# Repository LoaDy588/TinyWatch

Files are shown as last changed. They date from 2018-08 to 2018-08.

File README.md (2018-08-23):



### What is it?
Small digital wristwatch, powered by 8bit microcontroller, with 1.3inch 128x64 monochrome OLED display. Currently work in progress.

### Links
[Blog posts about development](https://loady.one/tag/tinywatch)

[Schematic, Rev2](https://files.loady.one/schematics/tiny_watch.pdf)

### BOM
|REF|Part|
|---|---|
|U1|MCP73831T-2ACI/OT|
|U2|MIC5504-2.8YM5|
|U3|MCP100-315I/TT|
|U4|PCF85063TP/1Z|
|U5|ATTINY1617-MFR|
|DISPLAY1|REX012864LWAP3N00000|
|J1|AMPHENOL 10118192-0001LF|
|Y1|ABRACON ABS07-166-32.768KHZ-T|
|SW1, SW2, SW3|C&K KXT321LHS|
|C1, C2, C9, C12, C14|4.7uF MLCC, 0603|
|C3, C5, C10, C11|1uF MLCC, 0603|
|C4, C6, C7, C8, C13|100nF MLCC, 0603|
|R1|8K2 Resistor, 0603|
|R2, R3, R4, R5, R6, R8|4K7 Resistor, 0603|
|R8, R9, R10|510K Resistor, 0603|

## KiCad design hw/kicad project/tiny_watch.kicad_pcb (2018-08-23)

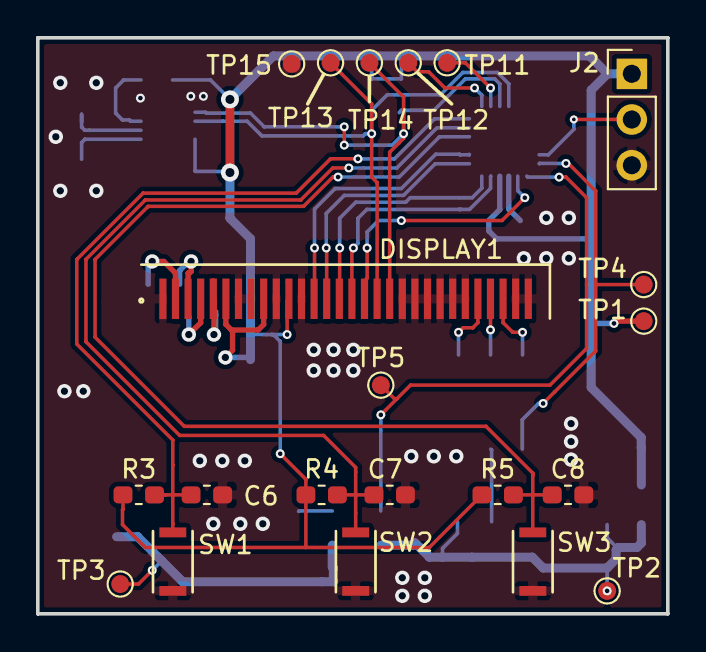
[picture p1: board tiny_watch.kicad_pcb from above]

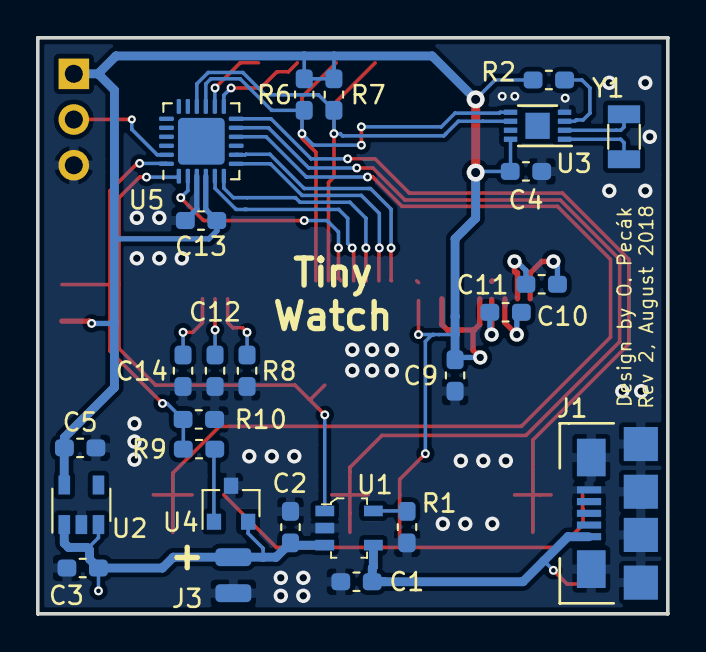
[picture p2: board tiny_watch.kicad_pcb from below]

Board: 2 copper layers, 35.0 x 32.0 mm, 47 parts (26 on the bottom side), 31 nets.

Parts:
C1, C2, C9, C12, C14: 4.7uF; C_0603_1608Metric_Pad1.05x0.95mm_HandSolder
C3, C5, C10, C11: 1uF; C_0603_1608Metric_Pad1.05x0.95mm_HandSolder
C4, C6, C7, C8, C13: 100nF; C_0603_1608Metric_Pad1.05x0.95mm_HandSolder
DISPLAY1: SH1106G_OLED; 30x_0.7-Pitch-display
J1: USB_B_Micro; AMPHENOL_10118192-0001LF-C
J2: PROG_HEADER; PinHeader_1x03_P2.54mm_Vertical
J3: BAT_CON; SMD_2_Wires
R1: 8K2; R_0603_1608Metric_Pad1.05x0.95mm_HandSolder
R2, R3, R4, R5, R6, R7: 4K7; R_0603_1608Metric_Pad1.05x0.95mm_HandSolder
R8, R9, R10: 510K; R_0603_1608Metric_Pad1.05x0.95mm_HandSolder
SW1, SW2, SW3: SW_Push; C_K KXT321LHS
TP1, TP2, TP3, TP4, TP5, TP11, TP12, TP13, TP14, TP15: TP; TestPoint_Pad_D1.0mm
U1: MCP73831T-2ACI_OT; SOT-753
U2: MIC5504-2.8YM5; SOT-23-5
U3: PCF85063TP; DFN-8-1EP_3x2mm_P0.5mm_EP1.36x1.46mm
U4: MCP100-315I/TT; SOT-23
U5: ATTiny1617/3217; QFN-24-1EP_4x4mm_P0.5mm_EP2.6x2.6mm
Y1: 32.768KHz; Crystal_SMD_3215-2Pin_3.2x1.5mm

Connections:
+5V: C1.2, J1.1, TP3.1, U1.4
BUTTON_1: C6.1, R3.2, SW1.2, U5.12
BUTTON_2: C7.1, R4.2, SW2.2, U5.11
BUTTON_3: C8.1, R5.2, SW3.2, U5.10
CHARGE_STAT: TP5.1, U1.1, U5.1
DISP_A0: DISPLAY1.15, U5.6
DISP_CS: DISPLAY1.13, U5.8
DISP_RDB: DISPLAY1.17, U5.2
DISP_RES: DISPLAY1.14, U5.7
DISP_WRB: DISPLAY1.16, U5.5
GND: C1.1, C2.1, C3.1, C4.1, C5.2, C6.2, C7.2, C8.2, C9.1, C12.1, C13.2, C14.1, DISPLAY1.1, DISPLAY1.7, DISPLAY1.8, DISPLAY1.10, DISPLAY1.12, DISPLAY1.20, DISPLAY1.21, DISPLAY1.22, DISPLAY1.23, DISPLAY1.24, DISPLAY1.25, DISPLAY1.29, DISPLAY1.30, J1.5, J1.6, J2.3, J3.2, R1.1, R8.1, R10.2, SW1.1, SW2.1, SW3.1, TP15.1, U1.2, U2.2, U3.4, U4.3, U5.3
LOW_BAT: R9.2, R10.1, TP4.1, U5.24
unnamed: C10.1, DISPLAY1.2
unnamed: C10.2, DISPLAY1.3
unnamed: C11.1, DISPLAY1.5
unnamed: C11.2, DISPLAY1.4
unnamed: C12.2, DISPLAY1.27
unnamed: C14.2, DISPLAY1.28
unnamed: DISPLAY1.26, R8.2
unnamed: R1.2, U1.5
unnamed: R2.1, U3.3
unnamed: R9.1, U4.1
unnamed: U3.1, Y1.1
unnamed: U3.2, Y1.2
SCL: DISPLAY1.18, R7.2, TP13.1, U3.6, U5.16
SDA: DISPLAY1.19, R6.2, TP14.1, U3.5, U5.15
UART_RX: TP12.1, U5.13
UART_TX: TP11.1, U5.14
UPDI: J2.2, U5.23
VBAT: C2.2, C3.2, J3.1, TP2.1, U1.3, U2.1, U2.3, U4.2
VDD: C4.2, C5.1, C9.2, C13.1, DISPLAY1.6, DISPLAY1.9, DISPLAY1.11, J2.1, R2.2, R3.1, R4.1, R5.1, R6.1, R7.1, TP1.1, U2.5, U3.8, U5.4

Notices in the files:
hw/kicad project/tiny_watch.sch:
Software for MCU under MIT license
